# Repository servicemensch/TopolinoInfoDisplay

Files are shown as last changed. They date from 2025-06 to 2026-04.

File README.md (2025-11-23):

# Topolino Info Display
Shows some details of the electronic system of the car, send it to a central (houseautomation-) system for further processing and status information. Additional a reversing light is controlled via a Bluetooht relaisbox.
Project Infomration could be found here:  [servicemensch.info](https://www.servicemensch.info/Offline/Topolino-Info-Display,ARTIKEL,15.html) (german)

## Drive screen
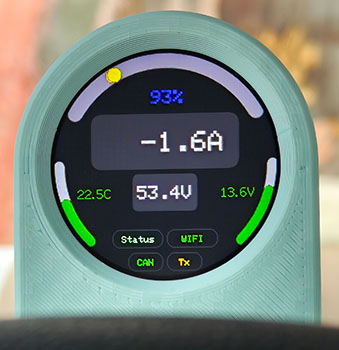
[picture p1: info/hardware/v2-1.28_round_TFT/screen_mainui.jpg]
drive screen


Shown information:
- Currently used power: multi-color bar + value (kW or Amps)
- Drive battery temperature: multi-color bar + value (°C)
- Drive battery voltage
- Drive battery state of charge (SoC %)
- 12V Battery voltage (shown before start driving)
- Average consumption (kWh) for the current trip
- Indicators for status, WIFI connection, Bluetooth, data transmition, CAN-Bus data communication

## Trip information
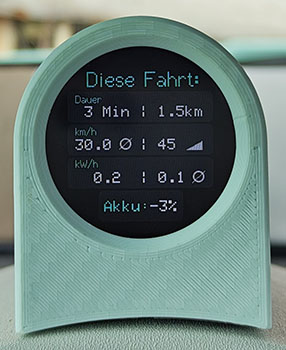
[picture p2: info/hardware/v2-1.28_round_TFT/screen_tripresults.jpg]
trip screen


Shown information:
- Trip duration in minutes
- Trip distance in km
- Maximum speed reached
- Average speed of the trip
- Consumed energy in kwh
- Consumed energy in percent (SoC)
- Average consumption (kwh / 100km)

## Charging information
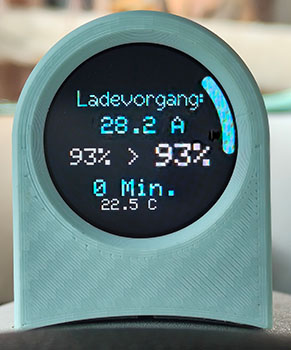
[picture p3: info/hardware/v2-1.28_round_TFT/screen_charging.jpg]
charging screen


Shown information during charging:
- Charging power in ampere
- SoC start value for this charge
- Current SoC value
- Minutes since charge started (duration)
- Drive battery temperature

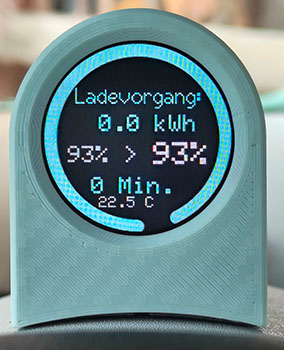
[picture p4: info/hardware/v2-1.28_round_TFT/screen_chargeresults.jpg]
charged screen


Shown information after charge ended:
- Power charged (kwh)
- Start Soc + end SoC of the charge
- Drive battery temperature
- Duration opf the charge (Minutes)

## Car compatibility:
- Fiat Topolino (Testcar: MY 2025)
- Opel Rocks-e
- Citroen Ami

---
# Hardware:
## Version 1 (inital Development enviroment / no longer used)
- [LilyGo T-Display S3](https://lilygo.cc/products/t-display-s3?variant=42284559827125) (ESP32 + 1,9" 8Bit LCD Screen)
- [MCP 2515 Can Bus module](https://www.az-delivery.de/products/mcp2515-can-bus-modul-1)
- 3D printed OBD2 plug

## Version 2 (current)
- [NodeMCU ESP32 Development Board 30 PIN](https://amzn.eu/d/eRXytsF)
- [1,28" TFT round GC9A01](https://amzn.eu/d/7S9U4s6)
- [MCP 2515 Can Bus module](https://www.az-delivery.de/products/mcp2515-can-bus-modul-1)
- 3D printed OBD2 plug
- [3D printed housing](https://makerworld.com/en/models/1659904-topolino-info-display-case#profileId-1755776)

### Wireing (Version 2):
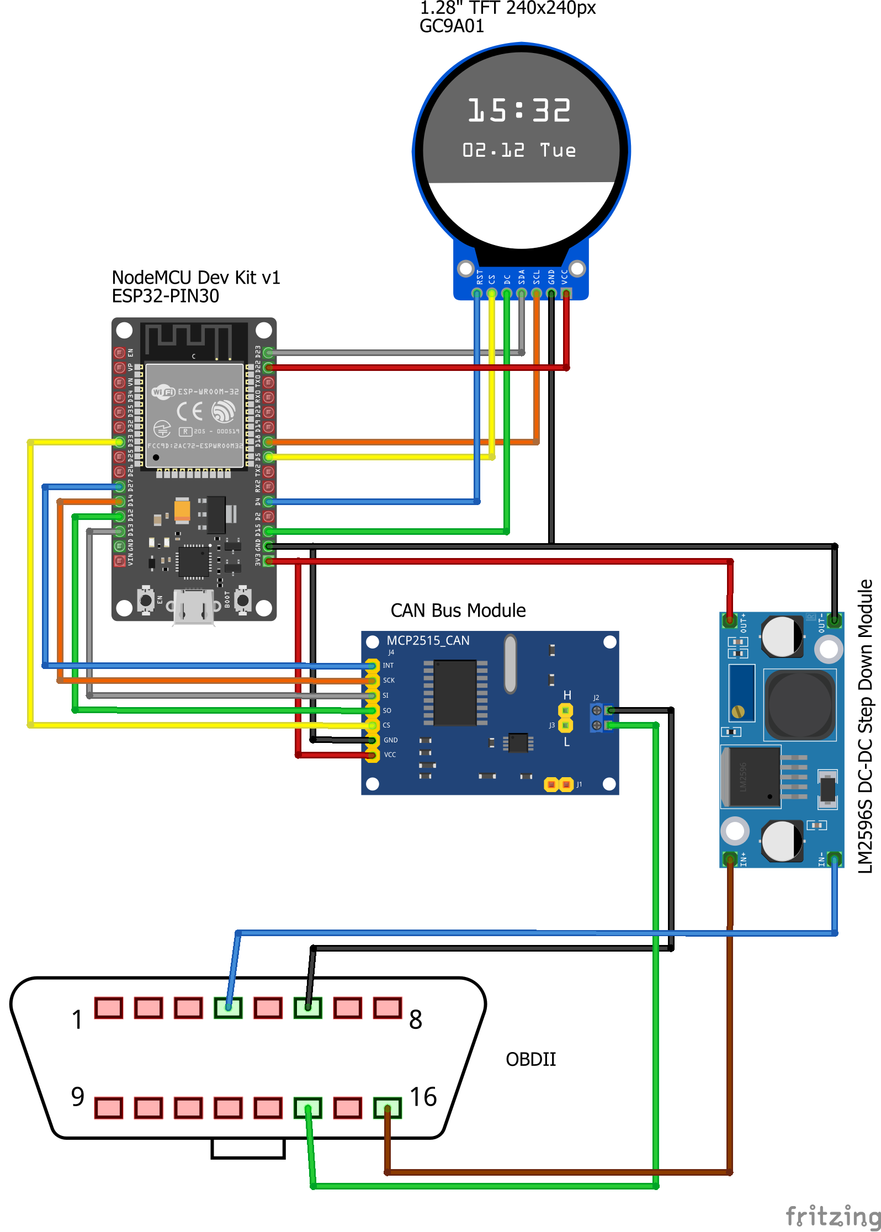
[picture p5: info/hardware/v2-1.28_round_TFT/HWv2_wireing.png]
v2 wireing diagram


---
# Software:
Build as **PlatformIO** project in **Visual Studio Code**.
Data transmission designed forseen to submit values to **ioBroker** via **SimpleAPI**.

## Libraries:
Standard:
- Arduino
- WIFI
- HTTPCLient
- SPI
- ArduinoOTA

Additional:
- [TFT_sSPI](https://github.com/Bodmer/TFT_eSPI)
- [ACAN2515](https://github.com/pierremolinaro/acan2515/)
- [urlencode](https://github.com/plageoj/urlencode)
- [TelnetStream](https://github.com/JAndrassy/TelnetStream)

## Configuration
Rename ./config/config_example.h to config.h and fill the values

## ioBroker integration
Data Send to "SimpleAPI" adapter via HTTP REST calls.

### States
| iobroker object | value|
|--|--|
| 0_userdata.0.topolino.12VBatt | Voltage of the 12V Battery system |
| 0_userdata.0.topolino.BattA | Drive battery currently consumed ampers |
| 0_userdata.0.topolino.BattTemp1 | Drive battery temperature sensor 1 |
| 0_userdata.0.topolino.BattTemp2 | Drive battery temperature sensor 2 |
| 0_userdata.0.topolino.BattV | Drive battery coltage |
| 0_userdata.0.topolino.Handbreak | Manual handbreaks set/ not set |
| 0_userdata.0.topolino.ODB | Total driven kilometers |
| 0_userdata.0.topolino.OnBoardChargerRemaining | Remaining minutes until charging is finished |
| 0_userdata.0.topolino.Ready | drive ready state |
| 0_userdata.0.topolino.RemainingKM | propossed kilometers left in drive battery |
| 0_userdata.0.topolino.SoC | State of Charge - drive battery in percent |
| 0_userdata.0.topolino.gear | selected gear |
| 0_userdata.0.topolino.speed | current speed |

Additionally the Trip data is reported to IOBroker.

---
# ⚠ Warning / Hint
**This is NOT a "ready to use" solution!**
You have to adapt it to your specific eviroment. You have to asamble the hardware by your own. You have compile it by your own. There is no support or guarantee! Take your reponsibility!

---
# Thank You
Thanky you to the project [AMI-Display](https://github.com/flrahe/AMI-Display) which inspired me to start this project and provided the information about the CAN-Messages of this "car".

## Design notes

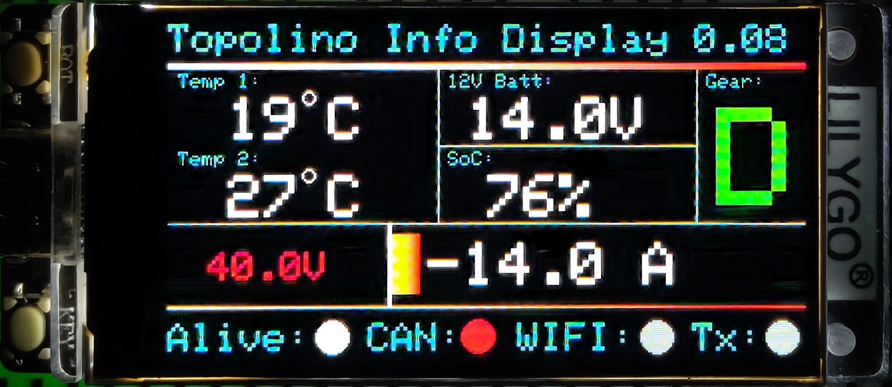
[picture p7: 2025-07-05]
info/hardware/v1-LilyGo_T-Display_S3/default_screen.jpg

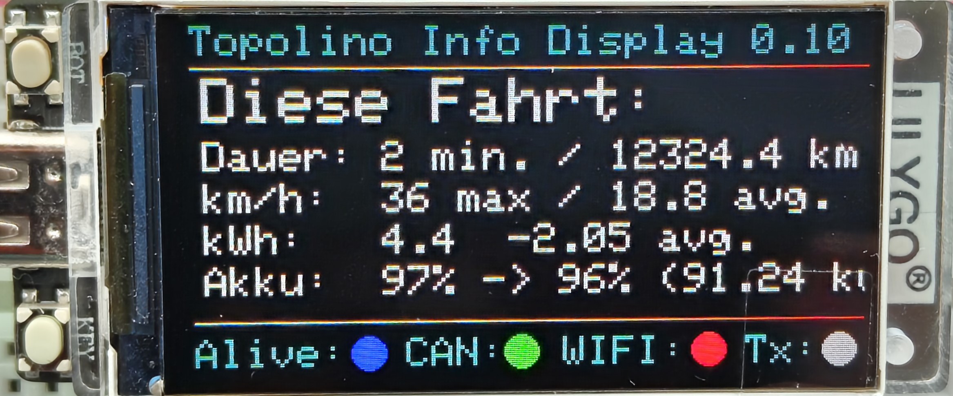
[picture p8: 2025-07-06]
info/hardware/v1-LilyGo_T-Display_S3/trip_screen.jpg

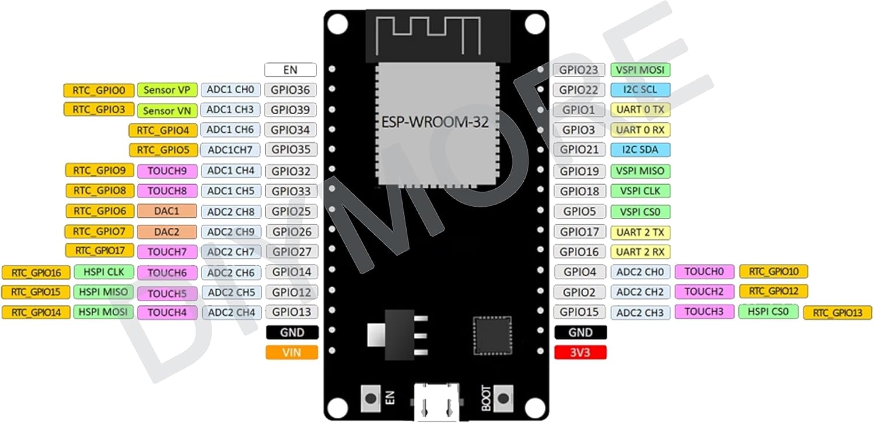
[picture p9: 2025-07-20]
info/hardware/v2-1.28_round_TFT/NodeMCU ESP32 DevBoard pinout.jpg

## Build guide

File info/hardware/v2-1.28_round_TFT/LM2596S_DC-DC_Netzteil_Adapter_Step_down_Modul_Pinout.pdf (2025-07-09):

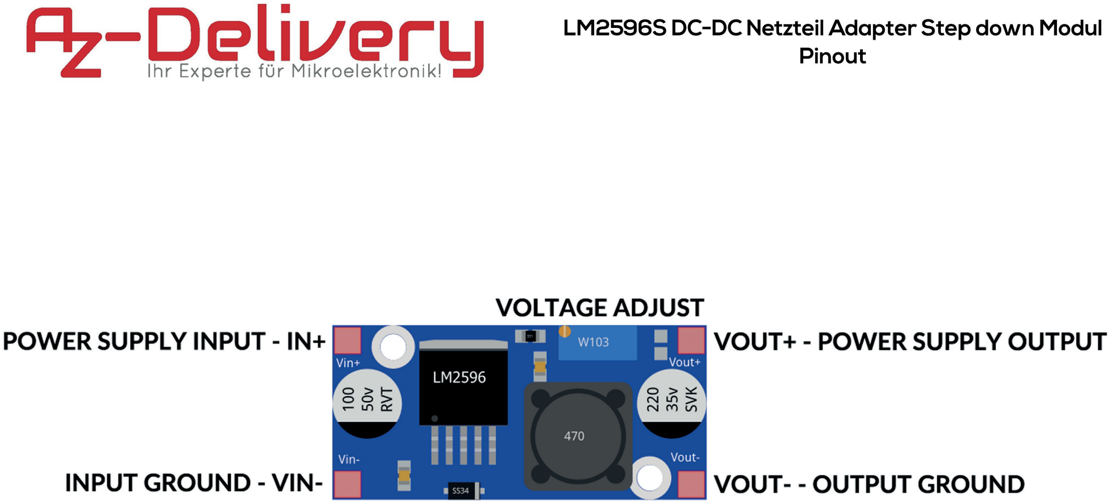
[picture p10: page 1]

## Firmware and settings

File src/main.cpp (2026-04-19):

#include <Arduino.h>
#include <WiFi.h>
#include <HTTPClient.h>
#include <spi.h>
#include <ArduinoOTA.h>
#include <TFT_eSPI.h>
#include <UrlEncode.h>
#include <ACAN2515.h>
#include <TelnetStream.h>
#include <img.h>

// Compiling options
//#define DEBUG
//#define DEBUGBT
#define BTClassic
//#define BTLowEnergy

#ifdef BTClassic
  #include <BluetoothSerial.h>
#endif

#ifdef BTLowEnergy
  #include <NimBLEDevice.h>
#endif

const char VERSION[] = "1.1c";

#define ShowConsumptionAsKW true
#define ShowChargeAsKW true

// Definitions
#define DISPLAY_POWER_PIN 22
#define CAN_INTERRUPT 27
#define CAN_CS 33
#define CAN_MOSI 13
#define CAN_MISO 12
#define CAN_SCK 14
#define CAN_8MHz 8UL * 1000UL * 1000UL
#define CAN_500Kbs 500UL * 1000UL
#define ONBOARD_LED 2

#define COLOR_ALMOSTBLACK 0x436c
#define COLOR_BACKGROUND 0x2104
#define COLOR_BG_GREEN 0x0140
#define COLOR_BG_RED 0x3000
#define COLOR_TOPOLINO 0x05f5
#define COLOR_GREY 0xa554
#define COLOR_LIGHTRED 0xfa08

struct trip {
  unsigned long startTime;
  unsigned long endTime;
  float startKM;
  float endKM;
  int maxSpeed;
  int startSoC;
  int endSoC;
  bool toSend;
};
struct CANValues {
  int ODO = 0;
  bool ODOUp = false;
  int Speed = 0;
  bool SpeedUp = false;
  int OBCRemainingMinutes = -1;
  bool OBCRemainingMinutesUp = false;
  float Battery = 0.0;
  bool BatteryUp = false;
  int Temp1 = -99;
  bool Temp1Up = false;
  int Temp2 = -99;
  bool Temp2Up = false;
  float Volt = 0;
  bool VoltUp = false;
  int SoC = 101;
  bool SoCUp = false;
  String Gear = "?";
  bool GearUp = false;
  int RemainingDistance = 0;
  bool RemainingDistanceUp = false;
  int Ready = -1; // 1=Ready, 0=Not Ready, -1=Unknown
  bool ReadyUp = false;
  float Current = 0;
  bool CurrentUp = false;
  int Handbrake = -1; // 1=On, 0=Off, -1=Unknown
  bool HandbrakeUp = false;
};
struct Charge {
  unsigned long startTime = 0;
  unsigned long endTime;
  int startSoC = 0;
  int endSoC = 0;
  int helperCircal = 0;
};

TFT_eSPI tft = TFT_eSPI();
SPIClass hspi = SPIClass(HSPI);
ACAN2515 can((int)CAN_CS, hspi, (int)CAN_INTERRUPT);

#ifdef BTClassic
  BluetoothSerial BT;
#endif  

#include "../config/config.h"

// Loops intervalls
unsigned long DisplayRefreshLastRun = 0;
const unsigned int DisplayRefreshInterval = 0.25 * 1000; 
unsigned long SendDataLastRun = 0;
const unsigned int SendDataInterval = 30 * 1000; 
unsigned long SerialOutputLastRun = 0;
const unsigned int TripRecordInterval = 1 * 1000;
unsigned long TripRecordingLastRun = 0;
unsigned long KeepAliveLastRun = 0;
unsigned long ReversingLightLastRun = 0;
unsigned long BTConnectLastRun = 0;

// Deep Sleep Timeout
#define DEEP_SLEEP_TIMEOUT 15 * 60 * 1000 // 15 minutes in milliseconds

// Bluetooth relais module
uint8_t BT_Slave_MAC[6] = {0x59, 0x95, 0xA4, 0x50, 0x71, 0x78}; // 59:95:A4:50:71:78
String BT_Slave_Name = "JDY-33-SPP";

// Globals
int CanError = 0;
unsigned long CanMessagesProcessed = 0;
unsigned long CanMessagesLastRecived = 0;
float Value_Battery_Current_Buffer = 0;
trip thisTrip; // Trip data structure
trip RTC_DATA_ATTR lastTrip1; // Last Trip data structure
trip RTC_DATA_ATTR lastTrip2; // Last Trip data structure
trip RTC_DATA_ATTR lastTrip3; // Last Trip data structure
trip RTC_DATA_ATTR lastTrip4; // Last Trip data structure
trip RTC_DATA_ATTR lastTrip5; // Last Trip data structure
CANValues canValues; // CAN values structure
Charge thisCharge;
bool TripActive = false;
bool DataToSend = false;
bool ChargeDataToSend = false;
unsigned long StatusIndicatorStatus = TFT_DARKGREY;
unsigned long StatusIndicatorCAN = TFT_DARKGREY;
unsigned long StatusIndicatorWIFI = TFT_DARKGREY;
unsigned long StatusIndicatorTx = TFT_DARKGREY;
unsigned long StatusIndicatorBT = TFT_DARKGREY;
bool IsSleeping = false;
bool IsCharging = false;
unsigned int BTReconnectCounter = 0;
bool BTisStarted = false;
float avgkWh = 10;
int SoCchangeDetection = 0;
int NoScreenupdateBefore = 0;
bool ScreenResetRequired = false;

// put function declarations here:
void CanConnect();
void CANCheckMessage();
bool WIFIConnect();
bool WIFICheckConnection();
void WIFIDisconnect();
void DisplayBoot();
void DisplayMainUI();
void DisplayTripResults();
void DisplayCharging();
void DisplayChargingResult();
void ConnectWIFIAndSendData();
bool SendDataSimpleAPI();
void SendRemoteLogSimpleAPI(String message);
bool SendChargeInfoSimpleAPI();
bool SendTripInfosSimpleAPI(trip tripToSend);
void SerialPrintValues();
void TripRecording();
void SleepLightStart();
void SleepDeepStart();
float average(float newvalue, float &buffer, float factor);
void DebugFakeValues();
void Log(String message, bool RemoteLog);
void Log(String message);
bool BTConnect(int timeout);
void BTDisconnect();
void BTSetRelais(int relais, bool state);
void BTScan();


// =====================================================================================================
// Make everything ready ===============================================================================
// =====================================================================================================
void setup() {
  // put your setup code here, to run once:
  Serial.begin(115200);
  Serial.flush();
  
  //Set Pins
  pinMode(ONBOARD_LED, OUTPUT); // Set the built-in LED pin as output

  pinMode(CAN_CS, OUTPUT);
  pinMode(CAN_INTERRUPT, INPUT_PULLUP);
  pinMode(DISPLAY_POWER_PIN, OUTPUT);

  //Deep Sleep config
  //esp_sleep_enable_timer_wakeup(DEEP_SLEEP_TIMEOUT);
  esp_sleep_enable_ext0_wakeup((gpio_num_t)CAN_INTERRUPT, 0); // Wake up on CAN interrupt

  digitalWrite(ONBOARD_LED, HIGH);

  // Turn on display power
  digitalWrite(DISPLAY_POWER_PIN, HIGH);
  delay(50);
  // Initialize display
  tft.init();
  tft.fillScreen(TFT_BLACK);
  delay(500);

  // Initiate CAN
  CanConnect(); 
  delay(500);
  CanMessagesLastRecived = millis();

  // Show Welcome Screen
  DisplayBoot();

  // Connect WIFI to enable OTA update at boot
  WIFIConnect();

  // Start Telnet stream for remote logging
  TelnetStream.begin();
 
  // Over The Air update config
  ArduinoOTA.setHostname("TopolinoInfoDisplayOTA");
  ArduinoOTA.begin();

  // Minimal Time for Boot Screen
  while (millis() < 3000) { delay(100); }

  // Setup sequence finished
  Log("TopolinoInfoDisplay started - Version: " + String(VERSION), true);
  int wakeupReason = esp_sleep_get_wakeup_cause();
  String message = "unknown wakeup";
  switch (wakeupReason) {
    case ESP_SLEEP_WAKEUP_EXT0:     message = "Wakeup caused by CAN message"; break;
    case ESP_SLEEP_WAKEUP_EXT1:     message = "Wakeup caused by external signal using RTC_CNTL"; break;
    case ESP_SLEEP_WAKEUP_TIMER:    message = "Wakeup caused by timer"; break;
    case ESP_SLEEP_WAKEUP_TOUCHPAD: message = "Wakeup caused by touchpad"; break;
    case ESP_SLEEP_WAKEUP_ULP:      message = "Wakeup caused by ULP program"; break;
    default:                        message = "Wakeup was caused by (power) reset"; break;
  }
  Log(message, true);  
  digitalWrite(ONBOARD_LED, LOW);
  tft.fillScreen(COLOR_BACKGROUND);

  #ifdef BTLowEnergy
    delay(1000);
    BTScan();
  #endif
#ifdef DEBUG
  // Debug
#endif

}

// =====================================================================================================
// Main Loop ===========================================================================================
// =====================================================================================================
void loop() {
  unsigned long currentMillis = millis();
  //Log(" - Tick: " + String(currentMillis));

  // Be Alive status
  if (currentMillis - KeepAliveLastRun >= 1000) {
    KeepAliveLastRun = currentMillis;
    digitalWrite(ONBOARD_LED, !digitalRead(ONBOARD_LED));

    if (StatusIndicatorStatus == TFT_WHITE) {
      if (TripActive) { StatusIndicatorStatus = TFT_YELLOW; }
      else if (canValues.Ready) { StatusIndicatorStatus = TFT_GREEN; }
    }
    else {
      StatusIndicatorStatus = TFT_WHITE;
    }
  }

  // No Screen refresh timeout
  if (currentMillis < NoScreenupdateBefore) {
    ScreenResetRequired = true;
  }
  else if (ScreenResetRequired) {
    ScreenResetRequired = false;
    tft.fillScreen(COLOR_BACKGROUND);
  }

  // Display Main UI / refresh Values
  if ((currentMillis - DisplayRefreshLastRun >= DisplayRefreshInterval) && !IsSleeping && !IsCharging && (currentMillis >= NoScreenupdateBefore)){
    DisplayRefreshLastRun = currentMillis;
    DisplayMainUI();
  }

  // Check CAN Messages
  if (can.available()) {
    StatusIndicatorCAN = TFT_YELLOW;
    CanMessagesLastRecived = currentMillis;
    CANCheckMessage();
  }
  else if (CanError) {
    Log("CAN Connect...");
    CanConnect();
  }
  else if ( CanMessagesLastRecived - currentMillis > 5000) { // If no CAN messages received for 5 seconds, set indicator to grey
    StatusIndicatorCAN =  TFT_DARKGREY;
  }

  #ifdef BTClassic
    // Check BT connection to Relais box
    if ((currentMillis - BTConnectLastRun > 5 * 60000 || (BTConnectLastRun == 0 && currentMillis > 15000)) && (canValues.Ready == 1 || (canValues.Gear == "N" || canValues.Gear == "R" || canValues.Gear == "D") )) { // Try to reconnect every 5 minutes
      BTConnectLastRun = currentMillis;
      if (BTisStarted) {
        if (!BT.connected()) {
          Log("BT Relais not connected! Reconnect Count: " + String(BTReconnectCounter), true);
          BTReconnectCounter++;
          if (BTReconnectCounter <= 2) {if ( BTConnect(3000)) {BTReconnectCounter = 0;} }
        }
      }
      else {
        BTConnect(30000);
      }
    }
    /* Deactivated due to always on BT Module
    if ((canValues.Ready != 1 || canValues.Gear == "-") && BTisStarted) { // Disconnect BT when car is not ready
      Log ("Car not ready - BT Relais OFF", true);
      BTSetRelais(1, false); // Turn off reversing light
      BTDisconnect();
    }
      */

    // Reversing Light
    if (currentMillis - ReversingLightLastRun >= 500 && BTisStarted) {
    ReversingLightLastRun = currentMillis;
    if (BT.connected()) {
      if (canValues.Gear == "R" && CanMessagesLastRecived - currentMillis < 3000) // Only activate if CAN messages are recent and car is in reverse
        {
        BTSetRelais(1, true); // Turn on reversing light
        StatusIndicatorBT = TFT_YELLOW;

        #ifdef DEBUG
          Log("Reversing Light ON");
        #endif
      }
      else
        {
        BTSetRelais(1, false); // Turn off reversing light
        StatusIndicatorBT = TFT_GREEN;

        #ifdef DEBUG
          Log("Reversing Light OFF");
        #endif
      }
    }
  }
  #endif

  // Check for new trip recording
  if (canValues.Speed > 0 && canValues.Ready == 1 && !TripActive && (currentMillis - CanMessagesLastRecived) < (5000)) {
    TripActive = true;
    Log("Trip started at " + String(thisTrip.startTime) + " with ODO: " + String(thisTrip.startKM));
    
    if (thisTrip.toSend == true) {
      lastTrip5 = lastTrip4;
      lastTrip4 = lastTrip3;
      lastTrip3 = lastTrip2; 
      lastTrip2 = lastTrip1;
      lastTrip1 = thisTrip;  // Save last trip for sending
      Log("Last Trip saved for later transmition", true);
    }
    // Reset Trip data
    thisTrip.startTime = 0;
    thisTrip.endTime = 0;
    thisTrip.startKM = 0;
    thisTrip.endKM = 0;
    thisTrip.maxSpeed = 0;
    thisTrip.startSoC = canValues.SoC;
    thisTrip.endSoC = canValues.SoC;
    thisTrip.toSend = false;
  } 
  if (currentMillis - TripRecordingLastRun >= TripRecordInterval && TripActive) {
    TripRecordingLastRun = currentMillis;
    TripRecording();
  }

  // Check current Trip has ended
  if ((canValues.Ready == 0 || canValues.Gear == "-" || canValues.Gear == "?" || (currentMillis - CanMessagesLastRecived) > (10000))  && TripActive) { //was: || (canValues.Gear == "N" && canValues.Handbrake && canValues.Speed == 0)
    TripActive = false;
    
    // Only trips longer than 100 meter will be transmitted
    if ( (float)((thisTrip.endKM - thisTrip.startKM) / 10) > 0.1) {
      thisTrip.toSend = true;
    }
    
    // Show Trip results
    DisplayTripResults();
    NoScreenupdateBefore = millis() + 30000; // No screen updates for 30 seconds to show trip results

  }

  // Check if new charge
  if (canValues.OBCRemainingMinutes >= 0 && canValues.Current > 0 && !IsCharging) {
    IsCharging = true;
    thisCharge.startSoC = canValues.SoC;
    thisCharge.startTime = currentMillis;
    tft.fillScreen(COLOR_BACKGROUND);

    Log("Charging started", true);
  }
  // Check if chareging has ended
  if (IsCharging && canValues.OBCRemainingMinutes == -1) {
    IsCharging = false;
    thisCharge.endSoC = canValues.SoC;
    thisCharge.endTime = currentMillis;
    if (((thisCharge.endTime - thisCharge.startTime) / 1000 / 60 ) > 5) { //only charges longer than 5 minutes will be transmitted
      ChargeDataToSend = true;
    }

    BTReconnectCounter = 0;
    Log("Charging has ended", true);

    // Show Charge end screen
    DisplayChargingResult();
    NoScreenupdateBefore = millis() + 60000; // No screen updates for 60 seconds to show charging results
    ConnectWIFIAndSendData();
  }

  // Is currently Charging  
  if (IsCharging && (currentMillis - DisplayRefreshLastRun >= DisplayRefreshInterval) && (currentMillis >= NoScreenupdateBefore))
  {
    DisplayRefreshLastRun = currentMillis;
    DisplayCharging();
  }

  // Send Data  
  if ((currentMillis - SendDataLastRun >= SendDataInterval) && (canValues.Speed < 1 && canValues.Handbrake) && (DataToSend || thisTrip.toSend || ChargeDataToSend)) //send in interval if ignition is off
  {
    SendDataLastRun = currentMillis;
    ConnectWIFIAndSendData();
  }
  else if (canValues.Speed > 1 && WiFi.status() != WL_NO_SHIELD)  { // deactivate tranismitting when driving
    #ifdef DEBUG
      Log("WIFI Status: " + String(WiFi.status()));
    #endif
    WIFIDisconnect();
    StatusIndicatorWIFI = TFT_DARKGREY;
    StatusIndicatorTx = TFT_DARKGREY;
  } 

  //Serial Output
  /*
  if (currentMillis - SerialOutputLastRun >= 5000) {
    SerialOutputLastRun = currentMillis;
    SerialPrintValues();
  }
  */

  //Check OTA Updates
  ArduinoOTA.handle();

  // Sleep modes
  if ((currentMillis - CanMessagesLastRecived) > (DEEP_SLEEP_TIMEOUT / 2) && !IsSleeping) {  
    SleepLightStart();
    BTReconnectCounter = 0;
  }
  if ((currentMillis - CanMessagesLastRecived) > DEEP_SLEEP_TIMEOUT) {  
    SleepDeepStart();
  }

  delay(25); //loop delay
}

// Functions ===========================================================================================
  
void CanConnect () {
  // CAN message filter
  /* Relevant IDs
  010110000001
  010110000010
  010110010011
  010110010100
  010110000000
  011100010011
  011100010100

  010100000000 - Filter
  010101100000 - Mask
  */
  const ACAN2515Mask rxm0 = standard2515Mask (0b010101100000,0,0); // Only ID is relevant for filtering
  const ACAN2515AcceptanceFilter canFilters[] = { 
    {standard2515Filter (0b010100000000,0,0)} // All Ids matching this filter
  };

  // CAN Module
  StatusIndicatorCAN = TFT_CYAN;
  hspi.begin(CAN_SCK, CAN_MISO, CAN_MOSI);
  ACAN2515Settings CanSettings (CAN_8MHz, CAN_500Kbs);
  CanSettings.mRequestedMode = ACAN2515Settings::ListenOnlyMode ;
  
  CanError = can.begin(CanSettings, [] { can.isr () ; });

  if ( CanError == 0) {
    Log("CAN-Module Initialized Successfully!");
    StatusIndicatorCAN = TFT_LIGHTGREY;
    } 
  else {
    Log("ERROR: Initializing CAN-Module failed! ErrCode: " + String(CanError));
    StatusIndicatorCAN = COLOR_LIGHTRED;
    }
  CanMessagesLastRecived = millis();
}
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

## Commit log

2025-06-24 Wireing digram added
    [Wireing.fzz]
2025-06-24 Update wireing
2025-06-24 next test
    [Wireing.fzz]
2025-06-24 First try to read CAN
    [Wireing.fzz]
2025-06-25 WIFI added
    [Wireing.fzz]
2025-06-25 with random values
    [Wireing.fzz]
2025-06-29 can message 12v
2025-07-01 specifi framework version
2025-07-02 use interrupt handling if ACAN lib
2025-07-02 thnking about Power consumption
2025-07-02 voltage convert
2025-07-05 indicator adaptions and display frame hints
2025-07-05 First Try with CAN Filtering
2025-07-05 fixing color of temp display
    [main.cpp]
2025-07-05 Trip recording added + fixes
    [main.cpp]
2025-07-08 interput pin to low
2025-07-09 added HW info of HW v2
    [Wireing.fzz]
2025-07-09 hwv2 wireing
    [HWv2 wireing.fzz]
2025-07-20 HW v2 update
    [HWv2 wireing.fzz]
2025-07-20 3.3v powersupplier
    [HWv2 wireing.fzz]
2025-07-22 enable display power off via GIPIO22
    [HWv2 wireing.fzz]
2025-07-25 Changed to Harware setup version 2
    [HWv2_wireing.fzz, Wireing.fzz]
2025-07-31 charging screen added
2025-07-31 Fixing charing circle + trip avg km/h
    [main.cpp]
2025-07-31 Akku Temp in charging screen
2025-07-31 fine tuning charging screen
2025-08-01 Added remote Logging but does not work
    [main.cpp]
2025-08-01 try to fix remote logging
    [main.cpp]
2025-08-08 Trip avg KWh fixed & Send Charging+Trip info to ioBroker added
    [main.cpp]
2025-08-12 Send Trip & Chargeing Data improved
2025-08-14 adjustment trip + Charging data send
2025-08-15 Fixed: SendTripInfos - blank due to string formating of value
    [main.cpp]
2025-08-17 Implement BT connection to reversing light; OTA not possible! changed partition table!
    [partiontable_ota_nofs_4MB.csv]
2025-08-18 Check BT Loop fixed
    [main.cpp]
2025-08-26 Show consumption per 100km if Trip is active on Right arc; fixed BT Indikator
    [main.cpp]
2025-08-27 changed BT beahivior; Main Ui fixes
    [main.cpp]
2025-08-29 fixed Status indicator UI + Trip maxSpeed
    [main.cpp]
2025-09-07 Tried to fix BT reconnect failures
    [main.cpp]
2025-09-10 Fixed crash, minor UI updates
    [main.cpp]
2025-11-18 Debug: negative Akku Temperatur fehlerhaft
2025-11-22 test fix neagtive drive battery values
    [main.cpp]
2025-11-22 drive batt temp fixed
    [main.cpp]
2025-12-23 Reverslight off when no can message for 3 > sec; fixing divided by zero for avgConsumption
    [main.cpp]
2026-04-12 Fix UI issue switching trip result to main
    [main.cpp]
2026-04-19 real fix UI background issue; charge value optional in kW
    [main.cpp]
2026-07-08 AVAS implemented + estimated remaining range (based on avg consumption of the current trip)
